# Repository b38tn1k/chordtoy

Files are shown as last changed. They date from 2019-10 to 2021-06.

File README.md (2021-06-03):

# chordtoy

not an arpeggiator :-P

A dual channel MIDI chord generator with 'strumming' on one channel

I am not that great at building cases, here are my v1 and v2 prototypes.
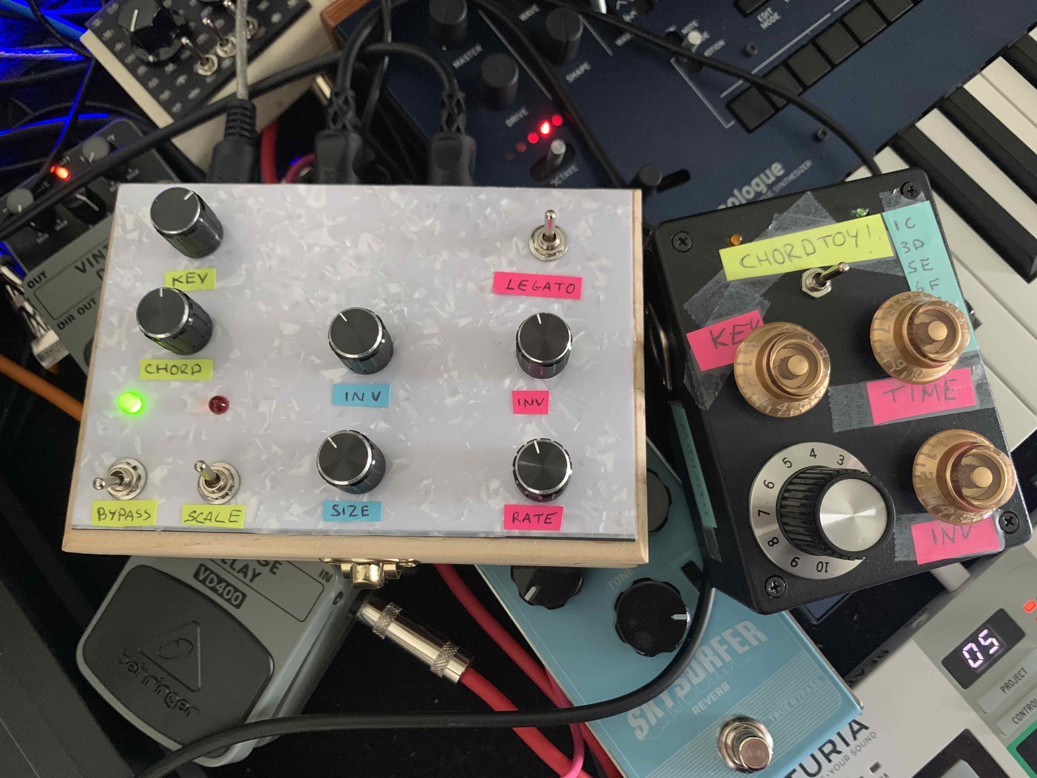
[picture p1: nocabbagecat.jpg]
no cat :(


[videos are easier than reading](https://www.youtube.com/playlist?list=PLZttbibA79ov0Y0J_pEOQnuLViuv8ho1e)

[how to install arduino midi library](https://github.com/FortySevenEffects/arduino_midi_library)

***built on a tested with MIDI Library version 4.3.1***

I wanted to play chords using the Arturia BeatStep Pro sequencer. This sits in the MIDI chain between the sequencer and the synth and uses the incoming MIDI note to stack a chord.*

## Features

- **Major / Minor Switch**. Major mode has a dominant 7th rather than major 7th chord, I haven't used it much.

- **Key Selector Pot:** Choose the key, other chords are mapped to scale for diatonic chords (I hope/think)

- **Chord Selector Pot:** Starting with the root note, add more notes to create a more complex sound. I tried to group the less complex sounds at low values and the more extreme sounds at high values. So, in Minor mode you can turn up to go from one note to a power chord to a minor chord to a minor 7, 9th, 11th, 13th.. with a couple more variations.

- **Inversion Mode Pot:** at zero the root note is at the bottom. At 100% the root note is at the top of the chord. Variations exist in between.

- **Strum Rate Pot:** When I first made this I just wanted to play simple block chords for techno-y sounding stabs on the DX. By accident I realized that the strummed chord can sound really nice and give some movement to a beat. Rhythms like [Legowelt](https://youtu.be/TGCxBVu1-sE) or [Flying Lotus](https://youtu.be/Pc0OaUQJtd4)... so at one extreme the chord plays all at once. At the other extreme the notes are plucked out one at a time slowly. Yes, like an arpeggiator. but no repeating or syncing cause I have a BeatStep that can keep time and play arpeggios :-)

- a **Legato Switch** changes the way MIDI noteoff messages are sent, allowing the strummed chord to ring out from a trigger or be cut short.

- a **Bypass Switch**, turn off the effect. More useful than turning everything down as in V1.

- a **Second MIDI Channel**. The ```MIDI_STRUM_CHANNEL``` does the 'strumming' chord effect. The ```MIDI_BLOCK_CHORD_CHANNEL``` is used to transmit block chords with the same notes as the Master chord, but with its own unique settings. It works nicely with my (newish) Behringer Crave in arp mode, giving me a 'free time' chord flourish from the DX and accompanying in time Arpeggios from the Crave. If you dont want the second channel stuff just don't let any devices listen on that channel and it should be fine, maybe tie the 'chord size' analog pin to ground :)

- **Second Inversion Mode**: as above but for the ```MIDI_BLOCK_CHORD_CHANNEL```, and with notes shifted 2 octaves cause I like it more.

- **Chord Size**: increase the number of notes in the ```MIDI_BLOCK_CHORD_CHANNEL``` by adding octaves above and below.

## Building

See below for my early prototypes, there is an ***in development*** kicad project included in this repo. Maybe someone good at EE can help? hmu!

Basically, you want to connect MIDI DINs to the Tx and Rx of the Arduino [I used this instructable](https://www.instructables.com/Send-and-Receive-MIDI-with-Arduino/). There are 6 pots, 3 switches and 2 LEDS in the current prototype, you can see the pin assignments in the .ino file.

Version 1 GPIOs per the .ino sketch:
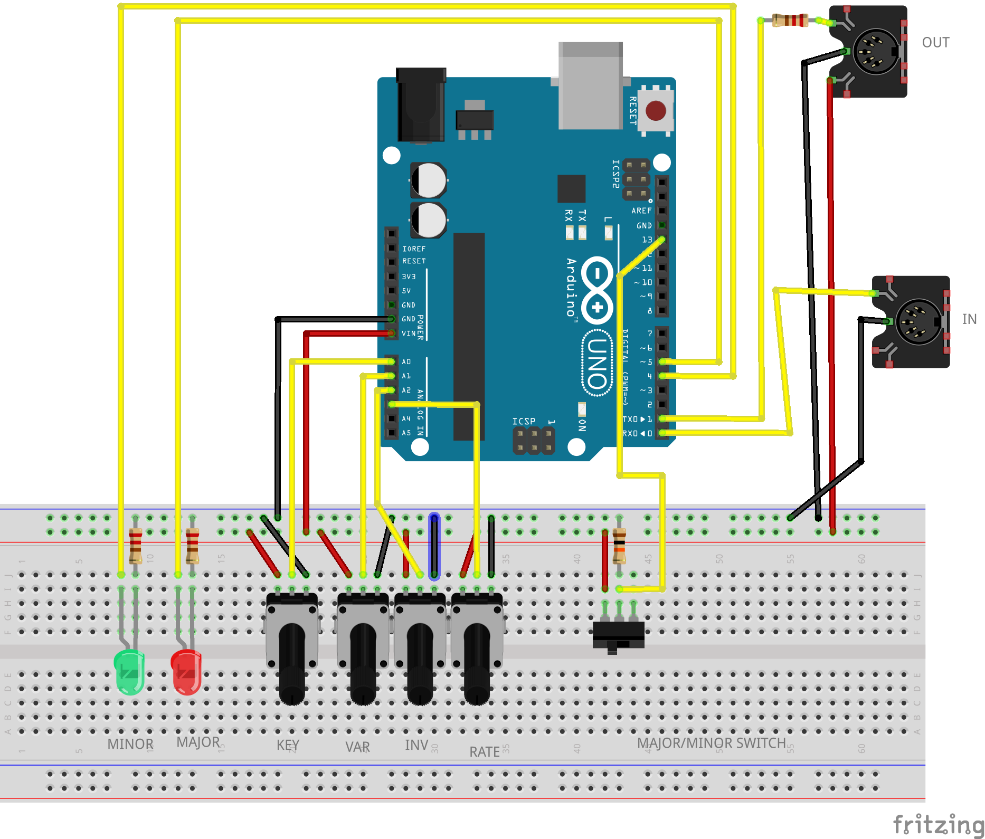
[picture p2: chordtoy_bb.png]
Circuit Diagram

Version 2 is similar with pot and switch IOs listed at top of the .ino file.

Prototype using a Pro Trinket (same pinouts as UNO) before I made it diatonic:
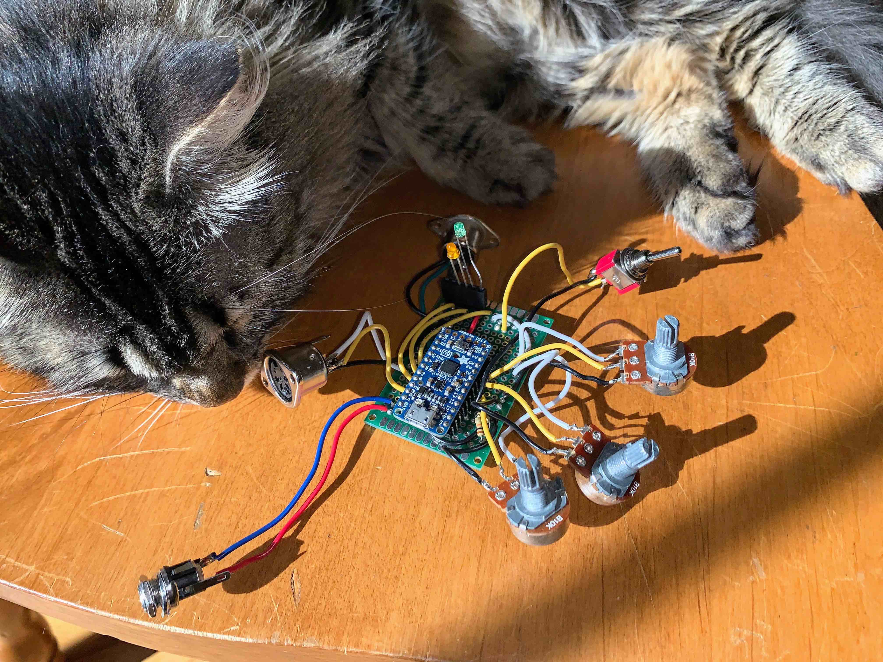
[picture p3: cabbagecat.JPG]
cat tax


## Almost TODOs, Maybe just ideas

- MIDI CC Control for the various pots and switches
- Does [FortySevenEffect](https://github.com/FortySevenEffects/arduino_midi_library) MIDI library support transport, tempo, etc pass through?

\* Akai and Oberheim used to make boxes that did this sort of thing and this functionality is now built into heaps of DAWs, possible some synths. my Yamaha DX doesn't

Thank you to David Fodel for testing, advice and motivation!

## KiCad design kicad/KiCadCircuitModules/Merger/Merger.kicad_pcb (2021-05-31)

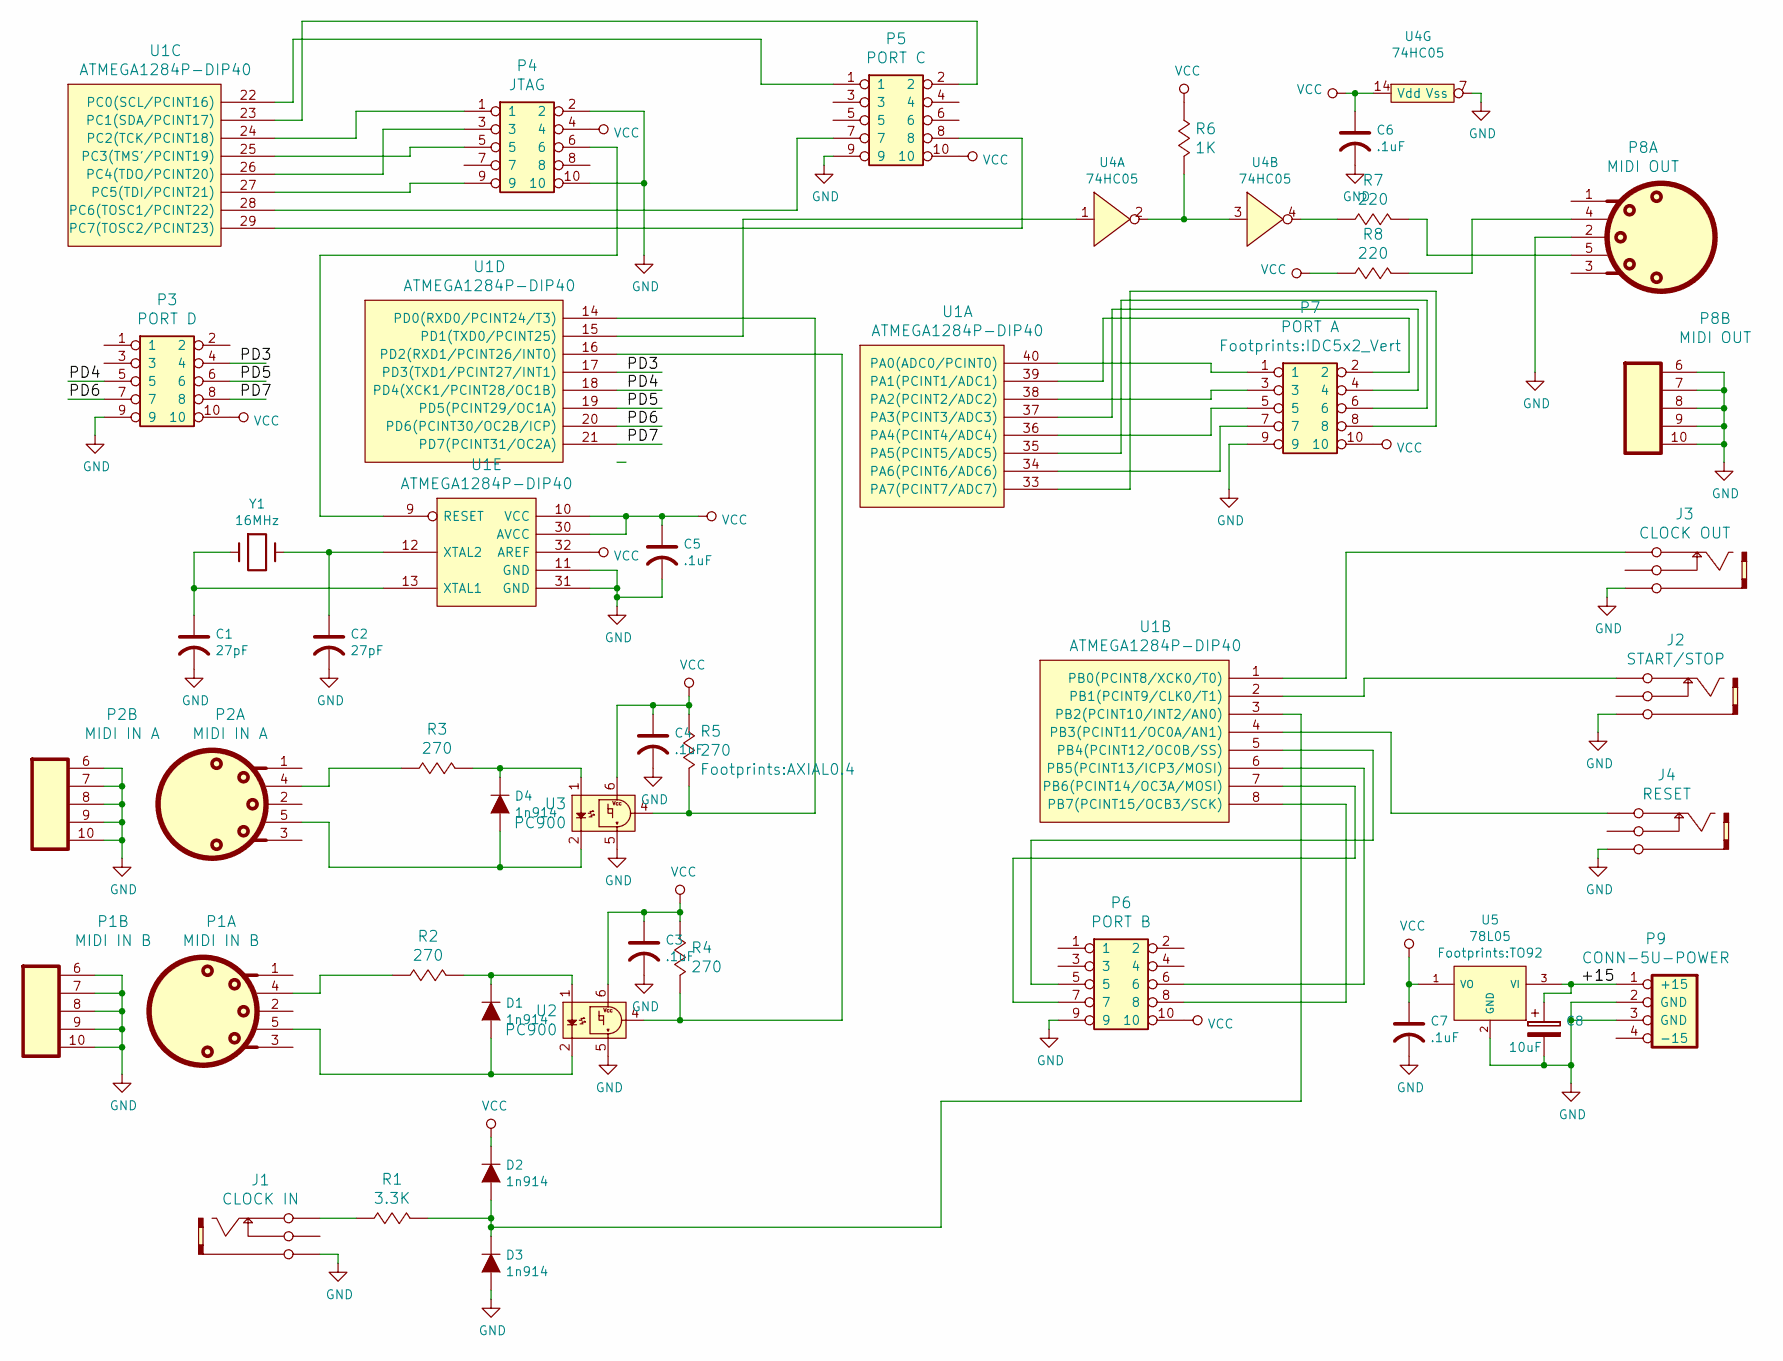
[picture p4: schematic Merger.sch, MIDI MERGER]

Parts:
C1, C2: 27pF; CAP-0.1
C3, C4, C5, C6, C7: .1uF; CAP-Bypass-0.3
C8: 10uF; C_Radial_D10_L13_P5
D1, D2, D3, D4: 1n914; DIODE0.4
J1: CLOCK IN; PHONE-SC112A
J2: START/STOP; PHONE-SC112A
J3: CLOCK OUT; PHONE-SC112A
J4: RESET; PHONE-SC112A
P1: MIDI IN B; DIN-5-PIN
P2: MIDI IN A; DIN-5-PIN
P3: PORT D; IDC5x2_Vert
P4: JTAG; IDC5x2_Vert
P5: PORT C; IDC5x2_Vert
P6: PORT B; IDC5x2_Vert
P7: PORT A; IDC5x2_Vert
P8: MIDI OUT; DIN-5-PIN
P9: CONN-5U-POWER; CONN-5U-POWER-RA
R1: 3.3K; AXIAL0.4
R2, R3, R4, R5: 270; AXIAL0.4
R6: 1K; AXIAL0.4
R7, R8: 220; AXIAL0.4
U1: ATMEGA1284P-DIP40; DIP-40.6
U2, U3: PC900; DIP-6.3
U4: 74HC05; DIP-14.3
U5: 78L05; TO92
Y1: 16MHz; XTAL

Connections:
/+15: C8.1, P9.1 (+15), U5.3 (VI)
/PD3: P3.4, U1.17 (PD3(TXD1/PCINT27/INT1))
/PD4: P3.5, U1.18 (PD4(XCK1/PCINT28/OC1B))
/PD5: P3.6, U1.19 (PD5(PCINT29/OC1A))
/PD6: P3.7, U1.20 (PD6(PCINT30/OC2B/ICP))
/PD7: P3.8, U1.21 (PD7(PCINT31/OC2A))
GND: C1.2, C2.2, C3.2, C4.2, C5.2, C6.2, C7.2, C8.2, D3.2 (A), J1.1 (Gnd), J2.1 (Gnd), J3.1 (Gnd), J4.1 (Gnd), P1.6 (Mounting_Pad), P1.7 (Mounting_Pad), P1.8 (Mounting_Pad), P1.9 (Mounting_Pad), P1.10 (Mounting_Pad), P2.6 (Mounting_Pad), P2.7 (Mounting_Pad), P2.8 (Mounting_Pad), P2.9 (Mounting_Pad), P2.10 (Mounting_Pad), P3.9, P4.2, P4.10, P5.9, P6.9, P7.9, P8.2, P8.6 (Mounting_Pad), P8.7 (Mounting_Pad), P8.8 (Mounting_Pad), P8.9 (Mounting_Pad), P8.10 (Mounting_Pad), P9.2 (GND), P9.3 (GND), U1.11 (GND), U1.31 (GND), U2.5 (GND), U3.5 (GND), U4.7 (Vss), U5.2 (GND)
unnamed: C1.1, U1.13 (XTAL1), Y1.1
unnamed: C2.1, U1.12 (XTAL2), Y1.2
unnamed: D1.1 (K), R2.2 (B), U2.1 (A)
unnamed: D1.2 (A), P1.5, U2.2 (C)
unnamed: D2.2 (A), D3.1 (K), R1.2 (B), U1.3 (PB2(PCINT10/INT2/AN0))
unnamed: D4.1 (K), R3.2 (B), U3.1 (A)
unnamed: D4.2 (A), P2.5, U3.2 (C)
unnamed: J1.3 (Tip), R1.1 (A)
unnamed: J2.3 (Tip), U1.2 (PB1(PCINT9/CLK0/T1))
unnamed: J3.3 (Tip), U1.1 (PB0(PCINT8/XCK0/T0))
unnamed: J4.3 (Tip), U1.4 (PB3(PCINT11/OC0A/AN1))
unnamed: P1.4, R2.1 (A)
unnamed: P2.4, R3.1 (A)
unnamed: P4.1, U1.24 (PC2(TCK/PCINT18))
unnamed: P4.3, U1.26 (PC4(TDO/PCINT20))
unnamed: P4.5, U1.25 (PC3(TMS'/PCINT19))
unnamed: P4.6, U1.9 (RESET)
unnamed: P4.9, U1.27 (PC5(TDI/PCINT21))
unnamed: P5.1, U1.22 (PC0(SCL/PCINT16))
unnamed: P5.2, U1.23 (PC1(SDA/PCINT17))
unnamed: P5.7, U1.28 (PC6(TOSC1/PCINT22))
unnamed: P5.8, U1.29 (PC7(TOSC2/PCINT23))
unnamed: P6.5, U1.5 (PB4(PCINT12/OC0B/SS))
unnamed: P6.6, U1.6 (PB5(PCINT13/ICP3/MOSI))
unnamed: P6.7, U1.7 (PB6(PCINT14/OC3A/MOSI))
unnamed: P6.8, U1.8 (PB7(PCINT15/OCB3/SCK))
unnamed: P7.1, U1.40 (PA0(ADC0/PCINT0))
unnamed: P7.2, U1.39 (PA1(PCINT1/ADC1))
unnamed: P7.3, U1.38 (PA2(PCINT2/ADC2))
unnamed: P7.4, U1.37 (PA3(PCINT3/ADC3))
unnamed: P7.5, U1.36 (PA4(PCINT4/ADC4))
unnamed: P7.6, U1.35 (PA5(PCINT5/ADC5))
unnamed: P7.7, U1.34 (PA6(PCINT6/ADC6))
unnamed: P7.8, U1.33 (PA7(PCINT7/ADC7))
unnamed: P8.4, R8.2 (B)
unnamed: P8.5, R7.2 (B)
unnamed: R4.2 (B), U1.16 (PD2(RXD1/PCINT26/INT0)), U2.4 (OUT)
unnamed: R5.2 (B), U1.14 (PD0(RXD0/PCINT24/T3)), U3.4 (OUT)
unnamed: R6.2 (B), U4.2, U4.3
unnamed: R7.1 (A), U4.4
unnamed: U1.15 (PD1(TXD0/PCINT25)), U4.1
VCC: C3.1, C4.1, C5.1, C6.1, C7.1, D2.1 (K), P3.10, P4.4, P5.10, P6.10, P7.10, R4.1 (A), R5.1 (A), R6.1 (A), R8.1 (A), U1.10 (VCC), U1.30 (AVCC), U1.32 (AREF), U2.6 (VCC), U3.6 (VCC), U4.14 (Vdd), U5.1 (VO)

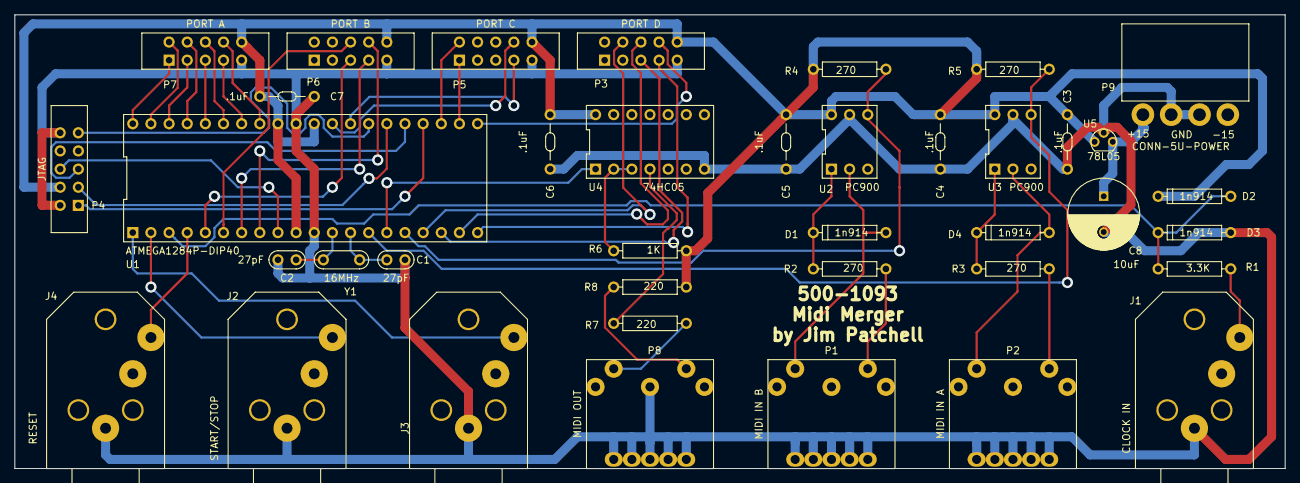
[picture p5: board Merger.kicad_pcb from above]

Board: 2 copper layers, 177.8 x 63.5 mm, 39 parts (0 on the bottom side), 49 nets.

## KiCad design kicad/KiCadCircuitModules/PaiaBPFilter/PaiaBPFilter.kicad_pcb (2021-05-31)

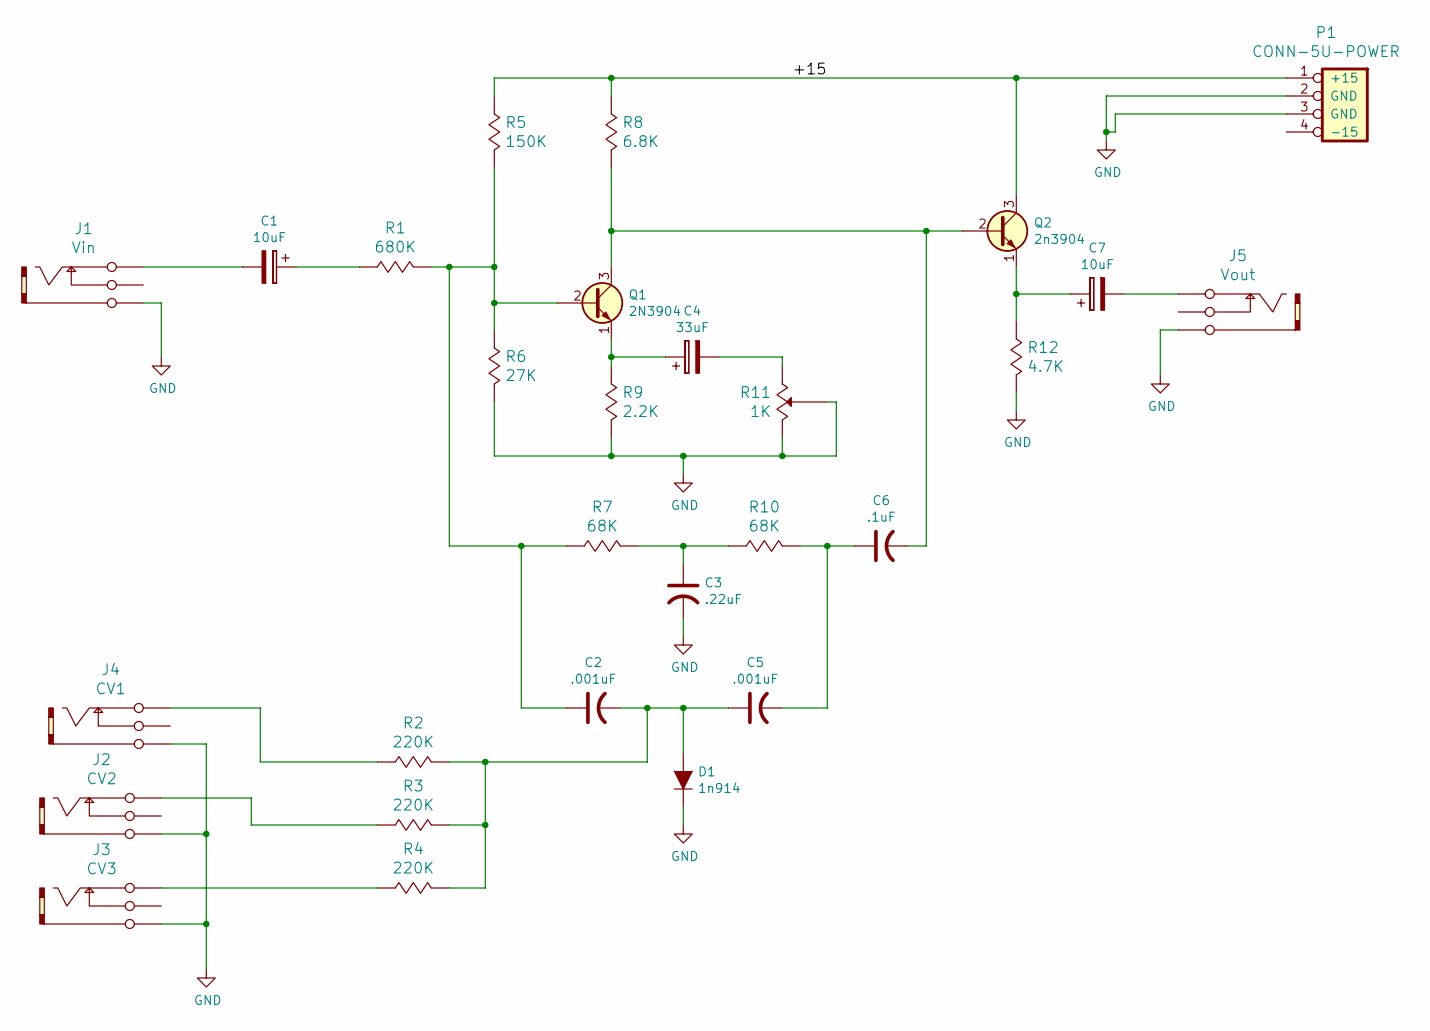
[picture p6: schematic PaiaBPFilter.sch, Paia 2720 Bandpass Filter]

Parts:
C1, C7: 10uF; C_Radial_D10_L20_P2.5
C2, C5: .001uF; CAP-GREENIE-0.2
C3: .22uF; CAP-GREENIE-0.2
C4: 33uF; C_Radial_D10_L20_P2.5
C6: .1uF; CAP-GREENIE-0.2
D1: 1n914; DIODE0.4
J1: Vin; PHONE-SC112A
J2: CV2; PHONE-SC112A
J3: CV3; PHONE-SC112A
J4: CV1; PHONE-SC112A
J5: Vout; PHONE-SC112A
P1: CONN-5U-POWER; CONN-5U-POWER-RA
Q1: 2N3904; TO92
Q2: 2n3904; TO92
R1: 680K; AXIAL0.4
R2, R3, R4: 220K; AXIAL0.4
R5: 150K; AXIAL0.4
R6: 27K; AXIAL0.4
R7, R10: 68K; AXIAL0.4
R8: 6.8K; AXIAL0.4
R9: 2.2K; AXIAL0.4
R11: 1K; POT-Alpha-24mm-RA
R12: 4.7K; AXIAL0.4

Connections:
/+15: P1.1 (+15), Q2.3 (C), R5.1 (A), R8.1 (A)
GND: C3.2, D1.1 (K), J1.1 (Gnd), J2.1 (Gnd), J3.1 (Gnd), J4.1 (Gnd), J5.1 (Gnd), P1.2 (GND), P1.3 (GND), R6.2 (B), R9.2 (B), R11.2 (Wiper), R11.3 (B), R12.2 (B)
unnamed: C1.1, R1.1 (A)
unnamed: C1.2, J1.3 (Tip)
unnamed: C2.1, Q1.2 (B), R1.2 (B), R5.2 (B), R6.1 (A), R7.1 (A)
unnamed: C2.2, C5.1, D1.2 (A), R2.2 (B), R3.2 (B), R4.2 (B)
unnamed: C3.1, R7.2 (B), R10.1 (A)
unnamed: C4.1, Q1.1 (E), R9.1 (A)
unnamed: C4.2, R11.1 (A)
unnamed: C5.2, C6.1, R10.2 (B)
unnamed: C6.2, Q1.3 (C), Q2.2 (B), R8.2 (B)
unnamed: C7.1, Q2.1 (E), R12.1 (A)
unnamed: C7.2, J5.3 (Tip)
unnamed: J2.3 (Tip), R3.1 (A)
unnamed: J3.3 (Tip), R4.1 (A)
unnamed: J4.3 (Tip), R2.1 (A)

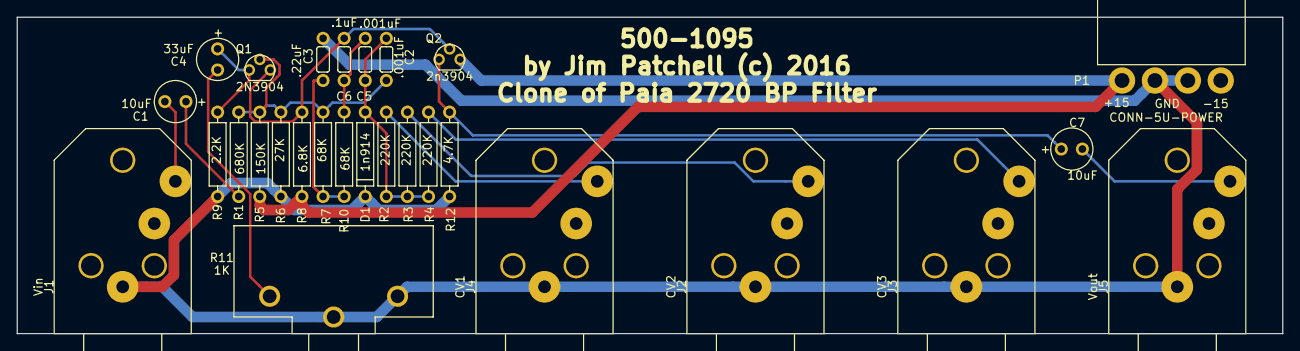
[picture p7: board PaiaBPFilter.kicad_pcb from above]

Board: 2 copper layers, 152.4 x 38.1 mm, 28 parts (0 on the bottom side), 16 nets.

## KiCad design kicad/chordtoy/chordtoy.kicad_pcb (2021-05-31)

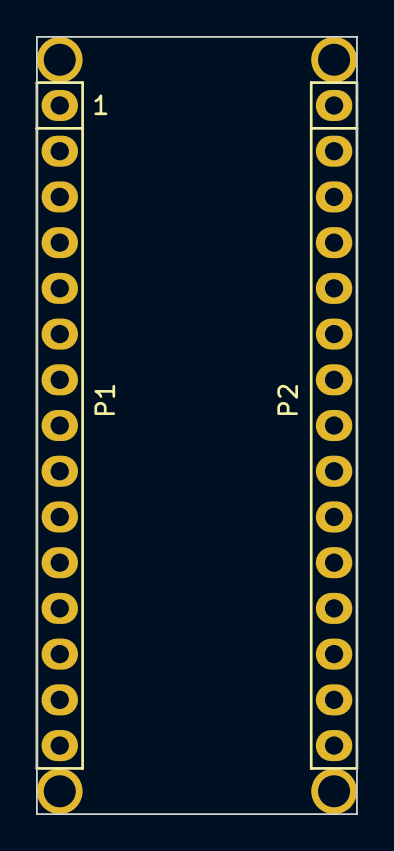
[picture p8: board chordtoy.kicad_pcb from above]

Board: 2 copper layers, 17.8 x 43.2 mm, 6 parts (0 on the bottom side), 2 nets, no tracks yet.

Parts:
P1: Digital; Socket_Strip_Arduino_1x15
P2: Analog; Socket_Strip_Arduino_1x15
P3, P4, P5, P6: CONN_01X01; 1pin_Nano

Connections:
/Reset: P1.3, P2.3
GND: P1.4, P2.2

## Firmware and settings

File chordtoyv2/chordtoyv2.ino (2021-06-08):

#include <MIDI.h>
//So this one does two MIDI channels, just connect two MIDI plugs to the output of the arduino, it should provide enough power
//or look for a blog on how to do it properly :-D

// MIDI SETTINGS - Change these as desired
//the strum channel
#define MIDI_STRUM_CHANNEL 3 
//the pad or arp channel
#define MIDI_BLOCK_CHORD_CHANNEL 5  

//IO for pots and switches
#define MAJOR_MINOR 11        //switch for major / minor
#define CHORD_POT 4           //pot to scroll throguh various chord shapes
#define INV_POT1 0            //pot to scroll through inversions for first channel
#define KEY_POT 5             //pot to scroll through western scale, enables selection of the root note for the major / minor mode, A = 0, Bb = 1, B = 2, ...
#define RATE_POT 1            //strum rate
#define LED_1 13              //major or minor signifier? IDK
#define LED_2 12              //major or minor signifier? IDK
#define BYPASS_SWITCH 10      //just pass normal MIDI through
#define LEGATO_SWITCH 9       //change note off mode a bit, also its not really legato, is something else 
#define INV_POT2 2            //pot to scroll through inversions for second channel
#define SIZE_POT 3            //pot to increase size of chord for second channel through addition of octaves above and below
#define TRNSPS_2ND_CHAN -24   //just my taste



//I dont think you need to worry about any other settings unless you wanna make some improvements
#define ANALOG_READ_RESOLUTION 1053.0
#define CHORD_VARIATIONS 15 // DX polyphony limit :-/
#define VOICES 7 // how many notes (not including root)
#define POLY 4
#define INVERSION_COUNT 6//hmm
#define THERE_ARE_12_NOTES_IN_WESTERN_MUSIC 12
#define MIDI_RANGE_WITH_SCALE 71
#define MAXIMUM_CHORD_SIZE 12 //that's pretty big though
MIDI_CREATE_DEFAULT_INSTANCE();

int chordSelection = 0;
int inversionSelection = 0;
int inversionSelection2 = 0;
byte thisChord[] = {0, 0, 0}; // DX polyphony limit //v2 update, turns up polyphony limit on the DX is more than 4, i cant remember how much more. 
byte thisChordSecond[] = {0, 0, 0}; // DX polyphony limit //v2 update, turns up polyphony limit on the DX is more than 4, i cant remember how much more. 
byte secondChord[] = {0, 0, 0, 0, 0, 0, 0, 0, 0, 0, 0, 0, 0, 0, 0, 0, 0}; // 12 notes and then major/minor, chord value, inversion, size
byte prevChord[] = {0, 0, 0};
unsigned long strumRate = 0;
bool trig = false;
byte chan, vel;
unsigned long currentMillis;
unsigned long pollPrevMillis = 0;
const long pollInterval = 100;
unsigned long trigPrevMillis;
int cur = 0; 
int curLim = 0;
int activeLED;
int inactiveLED;
int prevKey = 0;
int key = 0; //A = 0, Bb = 1, B = 2, ...
int keyCounter = 0;
long keyLEDPrevMillis = 0;
bool keyLEDStatus = false;
bool bypass = false;
bool bypassDebounce = false;
bool legato = false;
bool legatoDebounce = false;
int chordSize = 0;
byte scale[MIDI_RANGE_WITH_SCALE];
const int inversions[INVERSION_COUNT][POLY-1] = {{0, 0, 0}, {0, 0, -12}, {-12, 0, 0}, {-12, -12, 0}, {0, -12, -12}, {-12, -12, -12}};
//Reface DX Polyphony
const int chords[CHORD_VARIATIONS][VOICES] = {
    {0, 0, 0, 0, 0, 0}, 
    {0, 1, 0, 0, 0, 0}, 
    {1, 1, 0, 0, 0, 0}, 
    {1, 1, 1, 0, 0, 0}, 
    {1, 1, 0, 1, 0, 0}, 
    {1, 1, 0, 0, 1, 0}, 
    {0, 1, 1, 1, 0, 0}, 
    {0, 1, 1, 0, 1, 0}, 
    {1, 0, 1, 0, 1, 0},
    {0, 0, 1, 1, 1, 0},
    {0, 1, 1, 0, 1, 0}, 
    {0, 0, 0, 1, 1, 1},
    {0, 1, 1, 0, 0, 1}, 
    {1, 1, 0, 0, 0, 1},
    {0, 1, 0, 1, 0, 1}
    };
byte bank[VOICES];
const byte minorBank[] = {3, 7, 10, 14, 17, 21};
const byte dimBank[] = {3, 6, 12, 15, 18, 24};
const byte majorBank[] = {4, 7, 10, 12, 14, 17};
bool isMinor;
bool prevMode;

void setup() {
  pinMode(LED_1, OUTPUT);
  pinMode(LED_2, OUTPUT);
  pinMode(BYPASS_SWITCH, INPUT);
  pinMode(MAJOR_MINOR, INPUT);
  pinMode(LEGATO_SWITCH, INPUT);
  MIDI.setHandleNoteOn(handleNoteOn);
  MIDI.setHandleNoteOff(handleNoteOff);
//  MIDI.begin(MIDI_STRUM_CHANNEL); //bypass only works with this one channel. TODO: research MIDI Library more
  MIDI.begin(MIDI_CHANNEL_OMNI);
  pollInputs();
  toggleBank();
  prevMode = isMinor;
  prevKey = key;
}

void loop() {  
  currentMillis= millis();
  MIDI.read();
  if (currentMillis - pollPrevMillis >= pollInterval) {
    pollInputs();
    pollPrevMillis = currentMillis;
  }
  if (bypass == false) {
    if ((currentMillis - trigPrevMillis >= strumRate) && (cur < curLim)) {
      MIDI.sendNoteOn(thisChord[cur], vel, MIDI_STRUM_CHANNEL);
      trigPrevMillis = currentMillis;
      cur++;
    }
    if (prevMode != isMinor) {
      toggleBank();
      prevMode = isMinor;
    }
    // this is just to flash the stupid LED so you know what key!
    if (key != prevKey) {
      keyCounter = (key + 1) * 2;
      prevKey = key;
      keyLEDStatus = false;
      digitalWrite(activeLED, keyLEDStatus);
      keyLEDPrevMillis = currentMillis + 200;
      
    }
    if ((currentMillis-keyLEDPrevMillis>=200)&&(keyCounter >= 0)) {
      keyCounter -=1;
      keyLEDStatus = !keyLEDStatus;
      digitalWrite(activeLED, keyLEDStatus);
      keyLEDPrevMillis = currentMillis;
    }
  } else {
    if (currentMillis-keyLEDPrevMillis>=200) {
      keyLEDStatus = !keyLEDStatus;
      digitalWrite(LED_1, keyLEDStatus);
      digitalWrite(LED_2, keyLEDStatus);
      keyLEDPrevMillis = currentMillis;
    }
  }
  if (bypassDebounce != bypass) {
    bypassDebounce = bypass;
    digitalWrite(activeLED, HIGH);
    digitalWrite(inactiveLED, LOW);
    for (int k = 0; k < MAXIMUM_CHORD_SIZE; k++) {
      MIDI.sendNoteOff(secondChord[k], 0, MIDI_BLOCK_CHORD_CHANNEL); //clear out channel, faster than doing all notes every time which has a noticable lag
      secondChord[k] = 0;
    }
  }
  if (legatoDebounce != legato) {
    handleNoteOff(MIDI_STRUM_CHANNEL, 0, 0); //hmm, just try clear it out
    legatoDebounce = legato;
  }
}


void toggleBank() {
  if (isMinor == true) {
    assignBank(minorBank);
    activeLED = LED_1;
    inactiveLED = LED_2;
  } else {
    inactiveLED = LED_1;
    activeLED = LED_2;
    assignBank(majorBank);
  }
  digitalWrite(activeLED, HIGH);
  digitalWrite(inactiveLED, LOW);
}

void pollInputs() {
  isMinor = digitalRead(MAJOR_MINOR);
  bypass = digitalRead(BYPASS_SWITCH);
  legato = digitalRead(LEGATO_SWITCH);
  
  analogRead(RATE_POT);
  strumRate = long(ANALOG_READ_RESOLUTION - analogRead(RATE_POT)); 
  strumRate = strumRate/3;
  
  analogRead(CHORD_POT);
  float chordSensorVal = analogRead(CHORD_POT);
  chordSelection =  int(chordSensorVal * (CHORD_VARIATIONS/ANALOG_READ_RESOLUTION));
  
  analogRead(INV_POT1);
  float invSensorVal =analogRead(INV_POT1);
  inversionSelection = int(invSensorVal * (INVERSION_COUNT/ANALOG_READ_RESOLUTION));

  analogRead(INV_POT2);
  invSensorVal =analogRead(INV_POT2);
  inversionSelection2 = int(invSensorVal * (INVERSION_COUNT/ANALOG_READ_RESOLUTION));
  
  analogRead(KEY_POT);
  float keySensorVal = analogRead(KEY_POT);
  key = int(keySensorVal * (THERE_ARE_12_NOTES_IN_WESTERN_MUSIC/ANALOG_READ_RESOLUTION));

  analogRead(SIZE_POT);
  float chordSizeVal = analogRead(SIZE_POT);
  chordSize =int(chordSizeVal * (MAXIMUM_CHORD_SIZE/ANALOG_READ_RESOLUTION));
}

void handleNoteOn(byte channel, byte pitch, byte velocity) {
  if ((channel != MIDI_BLOCK_CHORD_CHANNEL && channel != MIDI_STRUM_CHANNEL) || bypass == true) {
    MIDI.sendNoteOn(pitch, velocity, channel);
  } else {
    if (channel == MIDI_STRUM_CHANNEL) {
      trigPrevMillis = millis();
      clearNCopyChord(pitch);
      cur = 0;
      curLim = 0;
      vel = velocity;
      trig = true;
      // create chord to be played in here
      // first in standard shape, pretend it not in the scale
      // note not in scale
      int j = 0;
      for (int i = 0; i < VOICES; i ++ ) {
        if (chords[chordSelection][i] == 1) {
          curLim++;
          thisChord[j] = bank[i] + pitch;
          j++;
        }
      }
      
      // rebuild in key maybe
      // bring it all the way to 0..12 range
      int lowNote = int(pitch) % 12;
      // figure out if it is in the scale;
      if ((lowNote - key) < 0) {lowNote += 12;}
      int interval = lowNote - key;
      
      // in a natural minor scale, the diatonic chords for iii, vi and vii are major
      if (isMinor == true && interval == 3 || interval == 5 || interval == 10) {
        curLim = 0;
        j = 0;
        for (int i = 0; i < VOICES; i ++ ) {
          if (chords[chordSelection][i] == 1) {
            curLim++;
            thisChord[j] = majorBank[i] + pitch;
            j++;
          }
        }
      }
    
        // in a natural minor scale, the ii is diminished
      if (isMinor == true && interval == 2) {
        curLim = 0;
        j = 0;
        for (int i = 0; i < VOICES; i ++ ) {
          if (chords[chordSelection][i] == 1) {
            curLim++;
            thisChord[j] = dimBank[i] + pitch;
            j++;
          }
        }
      }
    
      // in a major scale, the diatonic chords for ii, iii and vi are minor
      if (isMinor == false && interval == 2 || interval == 4 || interval == 9) {
        curLim = 0;
        j = 0;
        for (int i = 0; i < VOICES; i ++ ) {
          if (chords[chordSelection][i] == 1) {
            curLim++;
            thisChord[j] = minorBank[i] + pitch;
            j++;
          }
        }
      }
    
      // major has diminished vii
      if (isMinor == false && interval == 11) {
        curLim = 0;
        j = 0;
        for (int i = 0; i < VOICES; i ++ ) {
          if (chords[chordSelection][i] == 1) {
            curLim++;
            thisChord[j] = dimBank[i] + pitch;
            j++;
          }
        }
      }
      
      // apply inversion
    for (int k = 0; k < curLim; k++) {
        thisChord[k] = byte(int(thisChord[k]) + inversions[inversionSelection][k]);
      }
    }

    if (channel == MIDI_BLOCK_CHORD_CHANNEL) {
      ///NEW    
     int curLimSecond = 0;
     int j = 0;
     for (int i = 0; i < VOICES; i ++ ) {
       if (chords[chordSelection][i] == 1) {
         curLimSecond++;
         thisChordSecond[j] = bank[i] + pitch;
         j++;
       }
     }
     
     // rebuild in key maybe
     // bring it all the way to 0..12 range
     int lowNote = int(pitch) % 12;
     // figure out if it is in the scale;
     if ((lowNote - key) < 0) {lowNote += 12;}
     int interval = lowNote - key;
     
     // in a natural minor scale, the diatonic chords for iii, vi and vii are major
     if (isMinor == true && interval == 3 || interval == 5 || interval == 10) {
       curLimSecond = 0;
       j = 0;
       for (int i = 0; i < VOICES; i ++ ) {
         if (chords[chordSelection][i] == 1) {
           curLimSecond++;
           thisChordSecond[j] = majorBank[i] + pitch;
           j++;
         }
       }
     }
    
       // in a natural minor scale, the ii is diminished
     if (isMinor == true && interval == 2) {
       curLimSecond = 0;
       j = 0;
       for (int i = 0; i < VOICES; i ++ ) {
         if (chords[chordSelection][i] == 1) {
           curLimSecond++;
           thisChordSecond[j] = dimBank[i] + pitch;
           j++;
         }
       }
     }
    
     // in a major scale, the diatonic chords for ii, iii and vi are minor
     if (isMinor == false && interval == 2 || interval == 4 || interval == 9) {
       curLimSecond = 0;
       j = 0;
       for (int i = 0; i < VOICES; i ++ ) {
         if (chords[chordSelection][i] == 1) {
           curLimSecond++;
           thisChordSecond[j] = minorBank[i] + pitch;
           j++;
         }
       }
     }
    
     // major has diminished vii
     if (isMinor == false && interval == 11) {
       curLimSecond = 0;
       j = 0;
       for (int i = 0; i < VOICES; i ++ ) {
         if (chords[chordSelection][i] == 1) {
           curLimSecond++;
           thisChordSecond[j] = dimBank[i] + pitch;
           j++;
         }
       }
     }

        for (int k = 0; k < MAXIMUM_CHORD_SIZE; k++) {
          MIDI.sendNoteOff(secondChord[k], 0, MIDI_BLOCK_CHORD_CHANNEL); //clear out channel, faster than doing all notes every time which has a noticable lag
        }
        // second chord 
        secondChord[0] = pitch;
        // w/ inversion
        for (int k = 0; k < curLim; k++) {
          secondChord[k+1] = byte(int(thisChord[k] + TRNSPS_2ND_CHAN) + 2*(inversions[inversionSelection2][k]));
        }
        //this could be done in a loop but I like this arrangment so...
        secondChord[4] = byte(secondChord[0] + 12);
        secondChord[5] = byte(secondChord[0] - 12);
        secondChord[6] = byte(secondChord[1] + 12);
        secondChord[7] = byte(secondChord[1] - 12);
        secondChord[8] = byte(secondChord[2] + 12);
        secondChord[9] = byte(secondChord[2] - 12);
        secondChord[10] = byte(secondChord[3] + 12);
        secondChord[11] = byte(secondChord[3] - 12);
        //flags
        secondChord[12] = inversionSelection2;
        secondChord[13] = byte(isMinor);
        secondChord[14] = chordSize;
        secondChord[15] = chordSelection;

        for (int k = 0; k < chordSize; k++) {
          MIDI.sendNoteOn(secondChord[k], velocity, MIDI_BLOCK_CHORD_CHANNEL);
          Serial.flush();
        }
    }
  }
}

void handleNoteOff(byte channel, byte pitch, byte velocity) {

  if (bypass == true) {
    MIDI.sendNoteOff(pitch, velocity, channel);
  } else {
    if (legato == false) {
      cur = curLim;
    }
    if (channel == MIDI_STRUM_CHANNEL) {
      MIDI.sendNoteOff(pitch, 0, MIDI_STRUM_CHANNEL);
      for (int i = 0; i < VOICES; i ++ ) {
        MIDI.sendNoteOff(thisChord[i], 0, MIDI_STRUM_CHANNEL);
        MIDI.sendNoteOff(prevChord[i], 0, MIDI_STRUM_CHANNEL);
      }
    } else if (channel == MIDI_BLOCK_CHORD_CHANNEL) {
      MIDI.sendNoteOff(pitch, 0, MIDI_BLOCK_CHORD_CHANNEL);
      for (int i = 0; i < MAXIMUM_CHORD_SIZE; i ++ ) {
        MIDI.sendNoteOff(secondChord[i], 0, MIDI_BLOCK_CHORD_CHANNEL);
      }
    } else {
      MIDI.sendNoteOff(pitch, velocity, channel);
    }
  }
}


void assignBank(byte _bank[]) {
    for (int i = 0; i < VOICES; i++) {
      bank[i] = _bank[i];
    }
}

void clearChord(byte pitch) {
  for (int i = 0; i < POLY; i++) {
    thisChord[i] = pitch;
  }
}

void clearNCopyChord(byte pitch) {
  for (int i = 0; i < POLY; i++) {
    prevChord[i] = thisChord[i];
    thisChord[i] = pitch;
  }
}

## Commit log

2019-10-26 first run, wanna switch back fro a sec
2019-10-28 memory crash i think :-/
    [chordtoy.ino]
2020-05-30 added Note Off message for bypass switching channel 2, also a photo without a cat :-(
2021-05-31 more intentional seperation of channels, further dev on NoteOff required
    [ADSR.kicad_pcb, ADSR.sch, BasicPowerAmplifier.kicad_pcb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]

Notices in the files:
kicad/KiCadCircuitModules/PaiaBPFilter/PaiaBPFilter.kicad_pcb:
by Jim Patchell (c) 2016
